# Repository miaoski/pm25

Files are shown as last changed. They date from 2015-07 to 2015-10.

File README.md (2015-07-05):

# 空污偵測啦啦啦
* 2015.6.13 大松開的專案。Arduino IDE 的 project 丟這裡。
* Hackpad: https://g0v.hackpad.com/IoT-DIY-B1xkj9fUqqH

# 腳位
* Arduino A0 -- DN7C3CA006 Pin 2 VO
* Arduino A1 -- MQ9 SIG
* Arduino D2 -- DN7C3CA006 Pin 4 LED Vcc
* Arduino D3 -- DHT22 Data
* Arduino D8 -- 開關 (pull low 重設 AP 密碼)
* Arduino D9 -- ESP8266 reset pin

# LICENSE
本專案包含四個部份
* 電路的部份為 CC0
* Arduino 程式為 CC0
* ESP8266 部份為 MIT (修改自其它 MIT 專案及範例)
* Server 部份為 CC0

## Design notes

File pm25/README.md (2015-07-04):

請使用 luatool 上傳 lua 檔案到 ESP8266 上。

* 啟動後記得從 Arduino reset NodeMCU 才能獲得穩定的結果。
* FTDI 可以把 RX/TX 降到 3.3V, 但 Arduino 記得要做降壓電路。

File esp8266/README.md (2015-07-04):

本目錄和主程式無關。只是 PoC 而已。

使用 AT command 的 ESP8266 使用 115200bps 接在 Arduino Uno 的 TX/RX 上；Arduino 本身的 debug output 改用 soft serial 接在 pin 10, 11。

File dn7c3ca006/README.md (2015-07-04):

從 dn7c3ca006 讀出讀數後，使用 http://tw.taobao.com/item/44139051810.htm 提供的公式計算灰塵數。

本目錄和主程式無關。

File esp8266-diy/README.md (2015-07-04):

本目錄和主程式無關。

實作從頭到尾硬幹 AT command ，不使用 ESP8266 library。效果其實不太好。

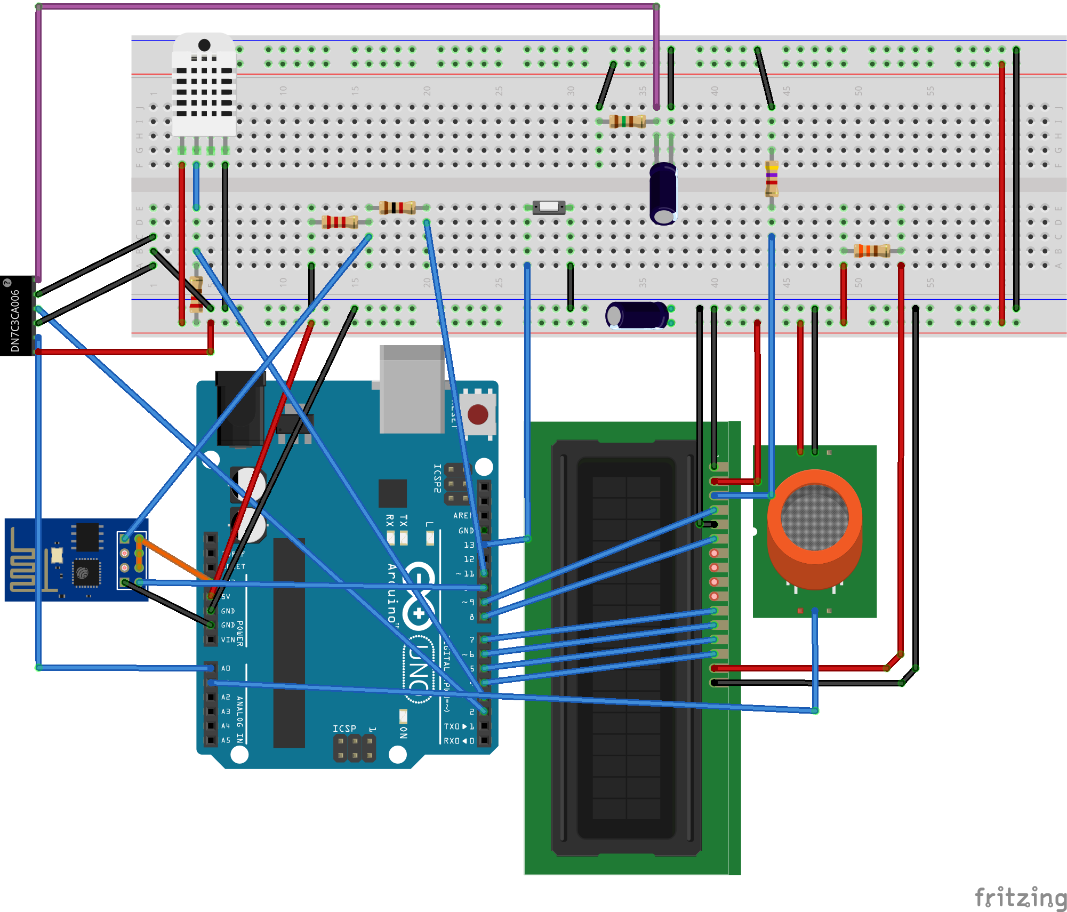
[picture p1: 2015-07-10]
pm25-sketch.png

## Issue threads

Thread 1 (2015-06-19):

WiFi doesn't send data every 5s

miaoski, 2015-06-19:
```
42.71.214.218 - - [19/Jun/2015 14:42:00] "GET /hum/73.00/temp/27.20/mq9/45.94/dn7/438.00 HTTP/1.0" 404 -
42.71.214.218 - - [19/Jun/2015 14:42:07] "GET /hum/72.30/temp/27.20/mq9/45.81/dn7/344.00 HTTP/1.0" 404 -
42.71.214.218 - - [19/Jun/2015 14:42:28] "GET /hum/72.00/temp/27.20/mq9/43.94/dn7/334.00 HTTP/1.0" 404 -
42.71.214.218 - - [19/Jun/2015 14:42:35] "GET /hum/70.60/temp/27.20/mq9/46.01/dn7/290.00 HTTP/1.0" 404 -
42.71.214.218 - - [19/Jun/2015 14:42:57] "GET /hum/70.20/temp/27.20/mq9/43.95/dn7/311.00 HTTP/1.0" 404 -
42.71.214.218 - - [19/Jun/2015 14:43:21] "GET /hum/69.40/temp/27.10/mq9/42.75/dn7/430.00 HTTP/1.0" 404 -
42.71.214.218 - - [19/Jun/2015 14:43:42] "GET /hum/67.40/temp/27.00/mq9/42.76/dn7/393.00 HTTP/1.0" 404 -
42.71.214.218 - - [19/Jun/2015 14:44:04] "GET /hum/67.00/temp/26.90/mq9/42.69/dn7/400.00 HTTP/1.0" 404 -
42.71.214.218 - - [19/Jun/2015 14:44:15] "GET /hum/65.90/temp/26.80/mq9/42.09/dn7/344.00 HTTP/1.0" 404 -
42.71.214.218 - - [19/Jun/2015 14:44:36] "GET /hum/65.40/temp/26.80/mq9/41.92/dn7/346.00 HTTP/1.0" 404 -
```

miaoski, 2015-06-19:
送出後不要 wifi.recv() ，直接 close 即可。
Solved by 0fdff48e06c81b0d612b788ca9c75ef281cd1e80

Closed 2015-06-19.

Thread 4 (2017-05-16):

Measurement Value Inconsistent

del-aire, 2017-05-16:
Thanks for sharing the code! I started to implement this without the temperature and humidity sensor, although I used fixed values but there seems to be an inaccuracy with the values I am getting from the dust sensor, over the space of a few minutes and in one location. See below output from the Arduino monitor.

Calibrated vs = 81.32
v0 = 62.44
hum = 30.00%   temp: 21.00C      dust_val = 0.00 mg/m3
v0 = 73.04
hum = 30.00%   temp: 21.00C      dust_val = 0.00 mg/m3
v0 = 101.04
hum = 30.00%   temp: 21.00C      dust_val = 57.77 mg/m3
v0 = 59.36
hum = 30.00%   temp: 21.00C      dust_val = 0.00 mg/m3
v0 = 100.72
hum = 30.00%   temp: 21.00C      dust_val = 56.84 mg/m3
v0 = 67.40
hum = 30.00%   temp: 21.00C      dust_val = 0.00 mg/m3
v0 = 93.36
hum = 30.00%   temp: 21.00C      dust_val = 35.27 mg/m3
v0 = 78.44
hum = 30.00%   temp: 21.00C      dust_val = 0.00 mg/m3
v0 = 94.60
hum = 30.00%   temp: 21.00C      dust_val = 38.91 mg/m3
v0 = 98.44
hum = 30.00%   temp: 21.00C      dust_val = 50.16 mg/m3
v0 = 104.16
hum = 30.00%   temp: 21.00C      dust_val = 66.91 mg/m3
v0 = 63.64
hum = 30.00%   temp: 21.00C      dust_val = 0.00 mg/m3
v0 = 92.20
hum = 30.00%   temp: 21.00C      dust_val = 31.87 mg/m3
v0 = 58.24
hum = 30.00%   temp: 21.00C      dust_val = 0.00 mg/m3
v0 = 102.04
hum = 30.00%   temp: 21.00C      dust_val = 60.70 mg/m3
v0 = 62.76
hum = 30.00%   temp: 21.00C      dust_val = 0.00 mg/m3
v0 = 98.16
hum = 30.00%   temp: 21.00C      dust_val = 49.34 mg/m3
v0 = 104.12
hum = 30.00%   temp: 21.00C      dust_val = 66.80 mg/m3
v0 = 81.56
hum = 30.00%   temp: 21.00C      dust_val = 0.70 mg/m3
v0 = 71.72
hum = 30.00%   temp: 21.00C      dust_val = 0.00 mg/m3
v0 = 97.32
hum = 30.00%   temp: 21.00C      dust_val = 46.88 mg/m3
v0 = 101.92
hum = 30.00%   temp: 21.00C      dust_val = 60.35 mg/m3
v0 = 107.44
hum = 30.00%   temp: 21.00C      dust_val = 76.52 mg/m3
v0 = 62.92
hum = 30.00%   temp: 21.00C      dust_val = 0.00 mg/m3
v0 = 97.52
hum = 30.00%   temp: 21.00C      dust_val = 47.46 mg/m3
v0 = 96.56
hum = 30.00%   temp: 21.00C      dust_val = 44.65 mg/m3
v0 = 91.36
hum = 30.00%   temp: 21.00C      dust_val = 29.41 mg/m3
v0 = 93.00
hum = 30.00%   temp: 21.00C      dust_val = 34.22 mg/m3
v0 = 97.08
hum = 30.00%   temp: 21.00C      dust_val = 46.17 mg/m3
v0 = 93.60
hum = 30.00%   temp: 21.00C      dust_val = 35.98 mg/m3
v0 = 69.20
hum = 30.00%   temp: 21.00C      dust_val = 0.00 mg/m3
v0 = 102.00
hum = 30.00%   temp: 21.00C      dust_val = 60.59 mg/m3
v0 = 105.64
hum = 30.00%   temp: 21.00C      dust_val = 71.25 mg/m3
v0 = 103.64
hum = 30.00%   temp: 21.00C      dust_val = 65.39 mg/m3
v0 = 104.80
hum = 30.00%   temp: 21.00C      dust_val = 68.79 mg/m3
v0 = 97.36
hum = 30.00%   temp: 21.00C      dust_val = 46.99 mg/m3
v0 = 85.92
hum = 30.00%   temp: 21.00C      dust_val = 13.48 mg/m3
v0 = 93.44
hum = 30.00%   temp: 21.00C      dust_val = 35.51 mg/m3
v0 = 99.48
hum = 30.00%   temp: 21.00C      dust_val = 53.20 mg/m3
v0 = 96.44
hum = 30.00%   temp: 21.00C      dust_val = 44.30 mg/m3
v0 = 82.24
hum = 30.00%   temp: 21.00C      dust_val = 2.70 mg/m3
v0 = 78.12
hum = 30.00%   temp: 21.00C      dust_val = 0.00 mg/m3
v0 = 90.68
hum = 30.00%   temp: 21.00C      dust_val = 27.42 mg/m3
v0 = 97.44
hum = 30.00%   temp: 21.00C      dust_val = 47.23 mg/m3
v0 = 103.28
hum = 30.00%   temp: 21.00C      dust_val = 64.34 mg/m3
v0 = 61.24
hum = 30.00%   temp: 21.00C      dust_val = 0.00 mg/m3
v0 = 70.52
hum = 30.00%   temp: 21.00C      dust_val = 0.00 mg/m3
v0 = 101.04
hum = 30.00%   temp: 21.00C      dust_val = 57.77 mg/m3
v0 = 96.72
hum = 30.00%   temp: 21.00C      dust_val = 45.12 mg/m3
v0 = 65.76
hum = 30.00%   temp: 21.00C      dust_val = 0.00 mg/m3
v0 = 107.52
hum = 30.00%   temp: 21.00C      dust_val = 76.76 mg/m3
v0 = 104.12
hum = 30.00%   temp: 21.00C      dust_val = 66.80 mg/m3
v0 = 66.16
hum = 30.00%   temp: 21.00C      dust_val = 0.00 mg/m3
v0 = 104.16
hum = 30.00%   temp: 21.00C      dust_val = 66.91 mg/m3
v0 = 81.48
hum = 30.00%   temp: 21.00C      dust_val = 0.47 mg/m3
v0 = 97.40
hum = 30.00%   temp: 21.00C      dust_val = 47.11 mg/m3
v0 = 104.00
hum = 30.00%   temp: 21.00C      dust_val = 66.45 mg/m3
v0 = 68.92
hum = 30.00%   temp: 21.00C      dust_val = 0.00 mg/m3
v0 = 95.96
hum = 30.00%   temp: 21.00C      dust_val = 42.89 mg/m3
v0 = 94.32
hum = 30.00%   temp: 21.00C      dust_val = 38.09 mg/m3
v0 = 86.24
hum = 30.00%   temp: 21.00C      dust_val = 14.41 mg/m3
v0 = 92.24
hum = 30.00%   temp: 21.00C      dust_val = 31.99 mg/m3
v0 = 93.52
hum = 30.00%   temp: 21.00C      dust_val = 35.74 mg/m3
v0 = 98.96
hum = 30.00%   temp: 21.00C      dust_val = 51.68 mg/m3
v0 = 93.80
hum = 30.00%   temp: 21.00C      dust_val = 36.56 mg/m3
v0 = 95.20
hum = 30.00%   temp: 21.00C      dust_val = 40.66 mg/m3
v0 = 110.12
hum = 30.00%   temp: 21.00C      dust_val = 84.38 mg/m3
v0 = 94.16
hum = 30.00%   temp: 21.00C      dust_val = 37.62 mg/m3
v0 = 92.60
hum = 30.00%   temp: 21.00C      dust_val = 33.05 mg/m3
v0 = 109.84
hum = 30.00%   temp: 21.00C      dust_val = 83.55 mg/m3
v0 = 88.52
hum = 30.00%   temp: 21.00C      dust_val = 21.09 mg/m3
v0 = 156.72
hum = 30.00%   temp: 21.00C      dust_val = 220.90 mg/m3
v0 = 139.24
hum = 30.00%   temp: 21.00C      dust_val = 169.69 mg/m3
v0 = 154.44
hum = 30.00%   temp: 21.00C      dust_val = 214.22 mg/m3
v0 = 148.12
hum = 30.00%   temp: 21.00C      dust_val = 195.70 mg/m3
v0 = 149.40
hum = 30.00%   temp: 21.00C      dust_val = 199.45 mg/m3
v0 = 165.52
hum = 30.00%   temp: 21.00C      dust_val = 246.68 mg/m3
v0 = 164.28
hum = 30.00%   temp: 21.00C      dust_val = 243.05 mg/m3
v0 = 143.60
hum = 30.00%   temp: 21.00C      dust_val = 182.46 mg/m3
v0 = 81.44
hum = 30.00%   temp: 21.00C      dust_val = 0.35 mg/m3
v0 = 78.24
hum = 30.00%   temp: 21.00C      dust_val = 0.00 mg/m3
v0 = 83.24
hum = 30.00%   temp: 21.00C      dust_val = 5.62 mg/m3
v0 = 65.04
hum = 30.00%   temp: 21.00C      dust_val = 0.00 mg/m3
v0 = 78.92
hum = 30.00%   temp: 21.00C      dust_val = 0.00 mg/m3
v0 = 81.16
hum = 30.00%   temp: 21.00C      dust_val = 0.00 mg/m3
v0 = 75.20
hum = 30.00%   temp: 21.00C      dust_val = 0.00 mg/m3
v0 = 88.24
hum = 30.00%   temp: 21.00C      dust_val = 20.27 mg/m3
v0 = 78.08
hum = 30.00%   temp: 21.00C      dust_val = 0.00 mg/m3
v0 = 78.48
hum = 30.00%   temp: 21.00C      dust_val = 0.00 mg/m3
v0 = 88.56
hum = 30.00%   temp: 21.00C      dust_val = 21.21 mg/m3

del-aire, 2017-05-25:
We've checked it out with an oscilloscope and it's seems that the fan is generating a lot of noise which could possibly influence the output from the Dn7c3ca006. So we removed it and power it through another channel. But it doesn't seem to affect the output that much. Then we continued verifying whether the device is calibrated correctly and this is where the problem is located according to us. Every time we tried calibrating it according to the Specification (measuring the Dust Value with the Fan turned off) we got another value (e.g. Calibrated Vs). Thus it seems that calibrating the device is harder than expected.

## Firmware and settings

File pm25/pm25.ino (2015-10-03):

// PM 2.5 Project
// https://github.com/miaoski/pm25
//
#include "DHT.h"
#include <SoftwareSerial.h>
#include <LiquidCrystal.h>

#define DHTTYPE DHT11
#define DHTPIN 2        // DHT pin to D2
#define SHARPPIN A0     // Pin 2 VO of dust sensor to Arduino A0
#define MQ9PIN   A1     // MQ9 SIG to Arduino A1
#define LEDPOWER 3      // Pin 4 LED VCC of dest sensor to Arduino D3
#define NODEMCU_RESET 9	// To NodeMCU reset pin to D9
#define APMODE_PIN 8	// Delete stored password in NodeMCU, GND pin D8
#define SSID_RESET 12	// Pull low to reset SSID / PassKey
#define MQ9_PREHEAT  90 // 90+10 seconds

#define samplingTime 460
#define deltaTime    40
#define sleepTime    9500

#undef  ESP8266_DBGMSG

// Initialize DHT sensor for normal 16mhz Arduino
DHT dht(DHTPIN, DHTTYPE);
SoftwareSerial esp8266(10, 11); // RX, TX
float vs;                       // Reference voltage of DN7C3CA006
LiquidCrystal lcd(4, 5, 6, 7, 8, 9);  // RS, E, D4, D5, D6, D7

void setup() {
  lcd.begin(16, 2);
  pinMode(LEDPOWER, OUTPUT);
  Serial.begin(9600);
  delay(100);
  esp8266.begin(9600);
  delay(100);
  Serial.println(F("g0v PM2.5 Project"));
  lcd.print("g0v PM2.5 Project");

  pinMode(SSID_RESET, INPUT_PULLUP);
  if(digitalRead(SSID_RESET) == 0) {
    Serial.println(F("Reset SSID/PassKey"));
    esp8266.println(F("tmr.stop(0)"));
    delay(100);
    esp8266.println(F("file.remove('config.lua')"));
    delay(100);
    esp8266.println(F("node.restart()"));
    Serial.println(F("Please set SSID/PassKey before resetting the device."));
    lcd.clear();
    lcd.print(F("Set SSID/Passkey and reset device"));
    while(1) {
      while(esp8266.available()) {
        Serial.write(esp8266.read());
      }
    }
  }

  // TODO: Calibrate Vs of DN7C3CA006
  vs = calibrate_DN7C();
  Serial.print(F("Calibrated vs = "));
  Serial.println(vs);
  
  // Reset NodeMCU
  /*
  pinMode(NODEMCU_RESET, OUTPUT);
  digitalWrite(NODEMCU_RESET, LOW);
  delay(100);
  digitalWrite(NODEMCU_RESET, HIGH);
  */

  delay(500);
  dht.begin();
}
  
void loop() {
  int i;
  float h = dht.readHumidity();
  float t = dht.readTemperature();
  float MQ9Value = readMQ9();
  float v0;
  float dn7c_h;
  float dustVal;

  // Value is meaningless before the sensor is hot
  if(millis() / 1000 < MQ9_PREHEAT) {
    MQ9Value = 0;
  }

  v0 = 0;
  for(i = 0; i < 25; i++) {
    v0 = v0 + read_dn7c3ca006();
    delay(10);
  }
  v0 = v0 / i;
  Serial.print("v0 = ");
  Serial.println(v0);

  if(h < 50) {
    dn7c_h = 1;
  } else {
    dn7c_h = 1 - 0.01467 * (h - 50);
  }
  if(v0 > vs) {
    dustVal = 0.6 * dn7c_h * (v0 - vs) * 5.0 * 1000.0 / 1024.0;
  } else {
    dustVal = 0;
  }
  
  Serial.print(F("hum = ")); 
  Serial.print(h);
  Serial.print(F("%   "));
  Serial.print(F("temp: ")); 
  Serial.print(t);
  Serial.print(F("C   "));
  Serial.print(F("MQ9_val: "));
  Serial.print(MQ9Value);
  Serial.print(F("   "));
  Serial.print(F("dust_val = "));
  Serial.print(dustVal);
  Serial.println(F(" mg/m3"));

  lcd.clear();
  lcd.print(h); lcd.print("%RH ");
  lcd.print(t); lcd.print("C");
  lcd.setCursor(0, 1);
  lcd.print(MQ9Value); lcd.print("  ");
  lcd.print(dustVal); lcd.print("mg/m3");
  
  esp8266.print(F("hum = "));
  esp8266.println(h);
  delay(150);
  esp8266.print(F("tmp = "));
  esp8266.println(t);
  delay(150);
  esp8266.print(F("mq9 = "));
  esp8266.println(MQ9Value);
  delay(150);
  esp8266.print(F("pm25 = "));
  esp8266.println(dustVal);

#ifdef ESP8266_DBGMSG
  while(esp8266.available()) {
    Serial.write(esp8266.read());
  }
#endif

  delay(1000);
}

float readMQ9() {
  int x;
  float sensor_volt; 
  float sensorValue;
  sensorValue = 0;
  for(x = 0 ; x < 100 ; x++) {
    sensorValue += analogRead(MQ9PIN);
  }
  sensorValue = sensorValue/x;
  return sensorValue;
}

float read_dn7c3ca006() {
  float dust = 0;
  digitalWrite(LEDPOWER, LOW);  // power on the LED
  delayMicroseconds(samplingTime);
  dust = analogRead(SHARPPIN);  // read the dust value
  delayMicroseconds(deltaTime);
  digitalWrite(LEDPOWER, HIGH); // turn the LED off
  delayMicroseconds(sleepTime);
  return dust;
}

float calibrate_DN7C() {
  float v0 = 0;
  unsigned short i;
  for(i = 0; i < 100; i++) {
    v0 = v0 + read_dn7c3ca006();
    delay(10);
  }
  v0 = v0 / i;
  return v0;
}

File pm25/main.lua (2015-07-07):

print ">>> main.lua"
http = require("http")

host = "220.135.254.63"	-- miaoski.idv.tw
port = 2080

hum = 0		-- Humidity
tmp = 0		-- Temperature
mq9 = 0		-- MQ9 voltage
pm25 = 0	-- DN7C3CA006 voltage

-- Send URL every 5s
tmr.alarm(0, 5000, 1, function()
	url = "id/" .. UUID .. "/hum/" .. hum .. "/tmp/" .. tmp .. "/mq9/" .. mq9 .. "/dn7/" .. pm25
	print("GET http://" .. host .. ":" .. port .. "/" .. url)
	http.get(host, port, url, {}, function(conn)
	end)
end)

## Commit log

2015-07-04 加入 PoC 目錄的說明
2015-07-04 Remove Arduino ESP8266 module
2015-07-04 GPIO2 pull high and fix timer typo
2015-07-04 Move reset pin to 9, and add delay for Lua
2015-07-05 fix license and make circuiting easy to read
    [pm25.ino]
2015-07-07 Pull low GPIO 5 to reset SSID/Pass
    [pm25.ino]
2015-07-09 Basic sketch without DN7C3CA006
    [pm25-sketch.fzz]
2015-07-10 add a place holder for DN7C3CA006
    [pm25-sketch.fzz]
2015-07-15 Use lcd.ino to calibrate dn7c3ca006
2015-07-21 should not use pin13, and nodemcu_reset is no longer used
    [pm25.ino]
2015-07-21 洞洞板的走線
    [stripboard.fzz]
2015-07-22 fix pins for arduino nano
    [pm25.ino]
2015-10-03 fix pin comments and calibrate
    [pm25.ino]
